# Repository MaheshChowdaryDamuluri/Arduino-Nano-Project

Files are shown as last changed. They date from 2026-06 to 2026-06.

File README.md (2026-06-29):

# ⚡ Custom Arduino Nano Compatible PCB Design Project

Welcome to the official repository for the **Custom Arduino Nano Hardware Clone** project. This repository houses the full programmatic schematic blueprints, advanced multi-layer stackup routing configurations, and fabrication-ready source materials engineered entirely within the KiCad design suite. 

Unlike a standard commercial breakout board, this implementation optimizes power rail stability, enhances differential signal impedance, and introduces precise physical test points for desktop diagnostic verification.

---

## 📐 1. Technical System Architecture

The hardware architecture systematically translates your top-level project settings into specialized component zones designed to reduce trace length and eliminate unwanted parasitic loops:

### 🧠 Core Microcontroller Node (`Arduino nano.kicad_sch`)
* **Processor Unit:** Features a high-performance 8-bit AVR microcontroller housed in an ultra-compact, surface-mount **QFN-32** package footprint.
* **System Clock:** Driven by a precision **16MHz ceramic resonator** (`Murata CSTNE`) to ensure predictable, jitter-free code execution timing.
* **ICSP Header Array:** Breaks out a standard 3-pin In-Circuit Serial Programming (ICSP) interface alongside standard vertical female pin-socket strips for effortless external bootloader flashing and pin mapping.

### 🔌 USB Telemetry & Serial Interface
* **Interface Bridge:** Built around the rugged **FT232RL SSOP-28** USB-to-Serial converter chip, delivering bulletproof stability over long debugging sessions.
* **Upstream Protection:** Protects your computer's USB controller using a resettable surface-mount **0603 Polyfuse** to clamp unexpected short-circuits instantly.
* **Differential Signaling:** Routes raw data lines using precise trace spacing down to test pads (`TP1` and `TP2`) for real-time oscilloscope signal inspection.

### ⚡ Power Supply & Linear Regulation Network
* **DC-DC Step-Down:** Incorporates a dedicated low-dropout (LDO) **LM1117MP-5.0 fixed linear regulator** in a robust SOT-223 package.
* **Filtering Topology:** Employs a multi-stage decoupling matrix combining polarized Tantalum bulk smoothing capacitors ($4.7\mu\text{F}$) with high-frequency $100\text{nF}$ ceramic filtering passives positioned right at the power input boundaries to block supply ripple spikes.
* **Input Isolation:** Implements an internal Schottky reverse-voltage protection diode to safely manage power handover between the external input pin and the desktop USB port.

---

## 🛠️ 2. PCB Layer Stackup & Layout Disciplines

The layout database shifts away from legacy double-sided prototyping to a high-speed **4-layer PCB architecture** configured inside the board setup:

1. **Top Layer (`F.Cu`):** High-density component landing networks and primary signal trace breakouts.
2. **Inner Layer 1 (`In1.Cu`):** Solid Ground Plane (`GND`) serving as a low-impedance return path to significantly reduce EM emissions.
3. **Inner Layer 2 (`In2.Cu`):** Specialized Power Grid distribution plane handling multiple system voltages.
4. **Bottom Layer (`B.Cu`):** Secondary routing pathways and clear status indicators.

* **🎨 Solder Mask Aesthetic:** Formatted for a sleek, premium **Blue Solder Mask** application over high-grade FR4 core material.
* **🚦 Status LEDs:** Incorporates four surface-mount visual telemetry indicators (Yellow for Power tracking, Green for Reset lines, and Red/Green options for system notifications).

---

## 📋 3. Project Bill of Materials (BOM)

| Designator | Component Quantity | Component Value | Package Footprint | Purpose / Function |
| :--- | :---: | :--- | :--- | :--- |
| **U1** | 1 | MCU Core Chip | QFN-32-1EP (5x5mm) | Primary Microcontroller Core |
| **U3** | 1 | FT232RL | SSOP-28_5.3x10.2mm | USB to Serial Communication Bridge |
| **U2** | 1 | LM1117MP-5.0 | SOT-223-3 (TabPin2) | +5V Low-Dropout Regulator |
| **F1** | 1 | Polyfuse (0603) | D_0603_1608Metric | Resettable Overcurrent Protection |
| **Y1** | 1 | 16MHz Resonator | CSTxExxV-3Pin (3.0x1.1mm) | Core Clock Source Oscillator |
| **J1** | 1 | USB_B_Mini | USB_Mini-B_Horizontal | System Power & Programming Interface |
| **SW1** | 1 | SW_Push | Panasonic_EVQPUK_EVQPUB | Master Hardware Reset Button |
| **C4, C9** | 2 | 4u7_16V | CP_EIA-3216-10_Kemet-I | Polarized Tantalum Smoothing Capacitors |
| **C1, C2, C5, C6** | 4 | 1u | C_0603_1608Metric | Ceramic Decoupling Passives |
| **C3, C7, C8, C10** | 4 | 100n | C_0603_1608Metric | High-Frequency Bypass Capacitors |
| **R1 - R7** | 7 | 1k | D_0603_1608Metric | Current Limiting Resistors |
| **D1 - D5** | 5 | LED Colors | LED_0805_2012Metric | Telemetry & Visual Status Indicators |

---

## 📂 4. Repository File Directory
```text
├── Arduino nano.kicad_pro    # Master project settings linking schematics & board layers
├── Arduino nano.kicad_sch    # Top-level interactive hardware electrical schema
├── Arduino nano.kicad_pcb    # Completed physical 4-layer trace layout matrix
├── Arduino nano.kicad_prl    # Project local display preferences & monitor settings
├── .gitignore                # Automatically generated rule patterns filtering out bak files
└── LICENSE                   # MIT Open-Source Hardware Licensing certification

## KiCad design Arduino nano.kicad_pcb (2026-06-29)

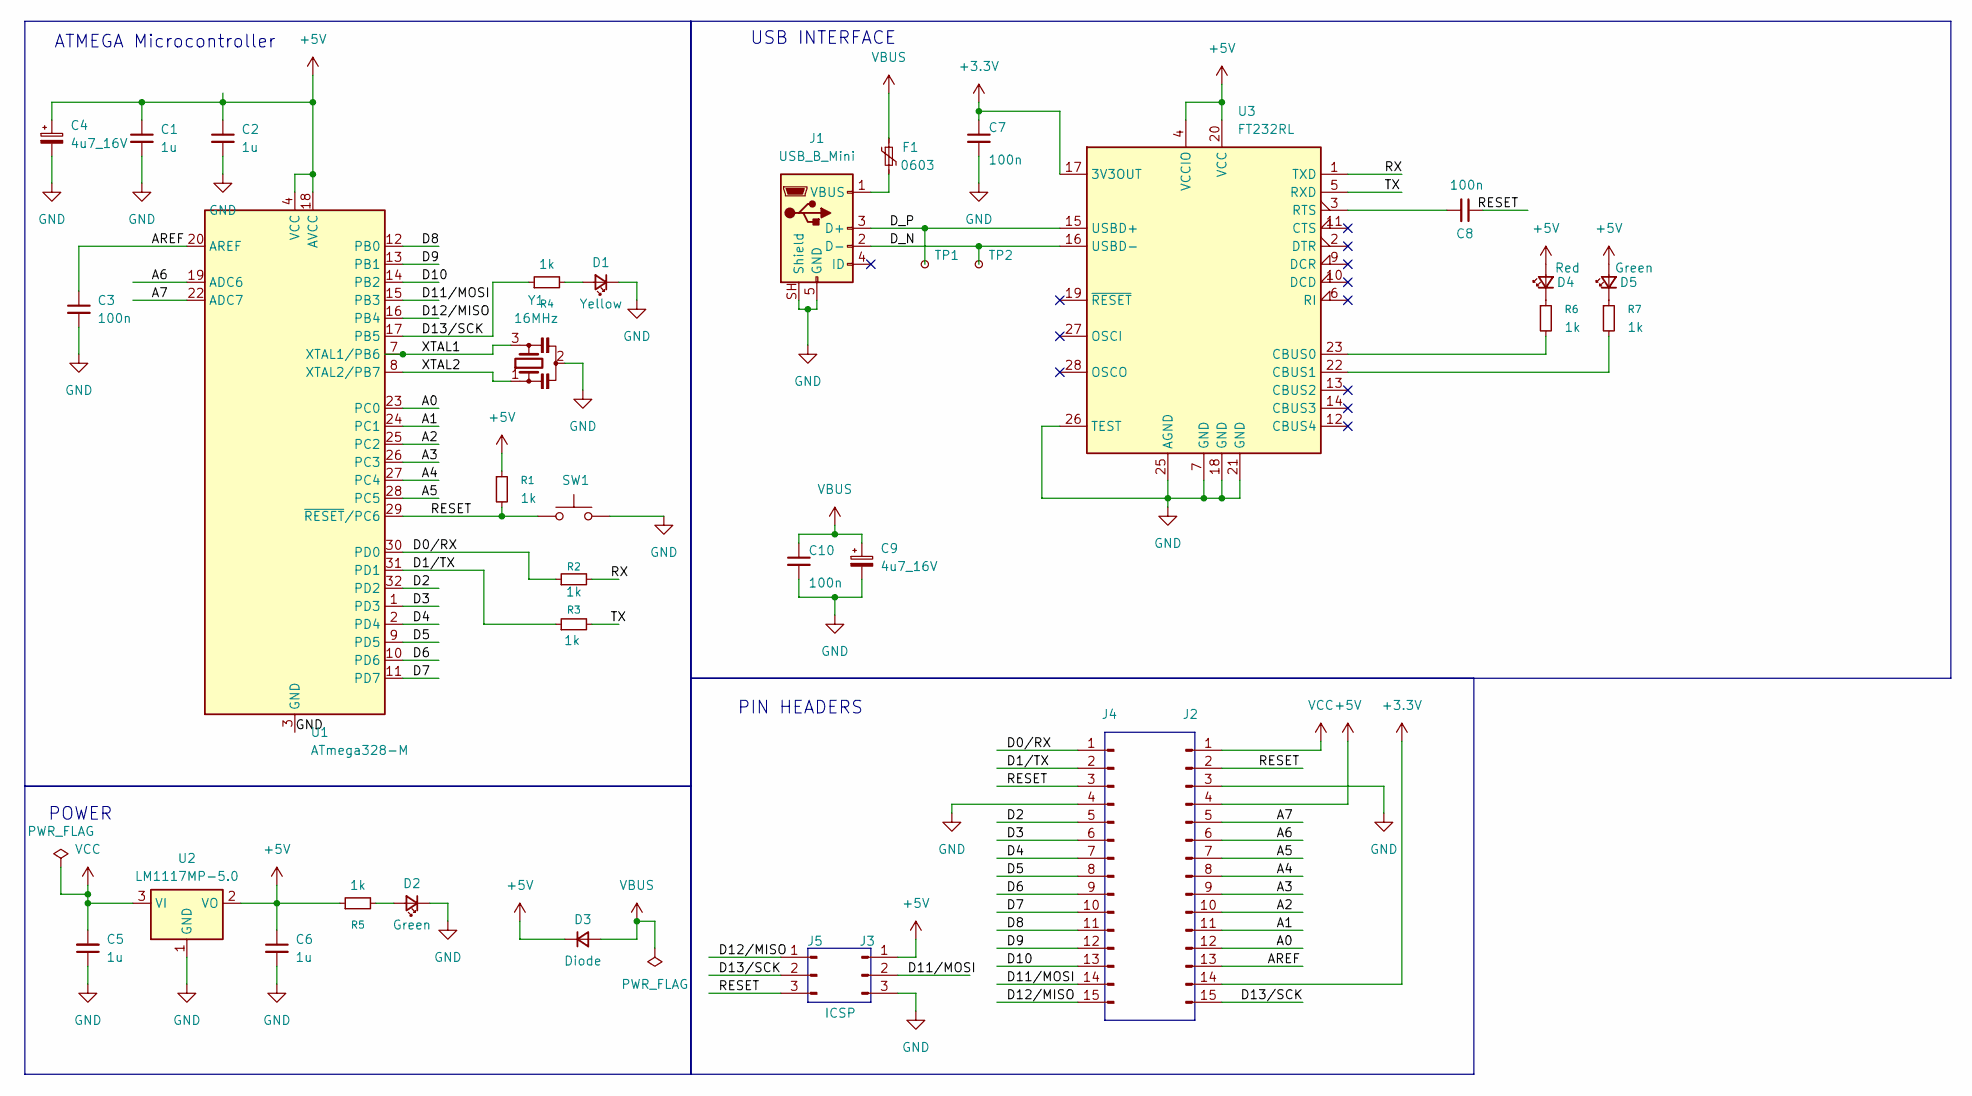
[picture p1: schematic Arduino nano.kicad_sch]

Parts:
C1, C2, C5, C6: 1u; C_0603_1608Metric
C3, C7, C8, C10: 100n; C_0603_1608Metric
C4, C9: 4u7_16V; CP_EIA-3216-10_Kemet-I
D1: Yellow; LED_0805_2012Metric
D2, D5: Green; LED_0805_2012Metric
D3: Diode; D_MicroSMP_AK
D4: Red; LED_0805_2012Metric
F1: 0603; D_0603_1608Metric
J1: USB_B_Mini; USB_Mini-B_Wuerth_65100516121_Horizontal
J2, J4: Conn_01x15_Pin; PinSocket_1x15_P2.54mm_Vertical
J3: ICSP; PinHeader_1x03_P2.54mm_Vertical
J5: Conn_01x03_Pin; PinHeader_1x03_P2.54mm_Vertical
R1, R2, R3, R4, R5, R6, R7: 1k; D_0603_1608Metric
SW1: SW_Push; Panasonic_EVQPUK_EVQPUB
TP1, TP2: TestPoint_Small; TestPoint_Pad_D1.0mm
U1: ATmega328-M; QFN-32-1EP_5x5mm_P0.5mm_EP3.1x3.1mm
U2: LM1117MP-5.0; SOT-223-3_TabPin2
U3: FT232RL; SSOP-28_5.3x10.2mm_P0.65mm
Y1: 16MHz; Resonator_SMD_Murata_CSTxExxV-3Pin_3.0x1.1mm

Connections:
+3.3V: C7.1, J2.14, U3.17 (3V3OUT)
+5V: C1.1, C2.1, C4.1, C6.1, D3.1 (K), D4.2 (A), D5.2 (A), J2.4, J3.1, R1.1, R5.1, U1.4 (VCC), U1.6 (VCC), U1.18 (AVCC), U2.2 (VO), U3.4 (VCCIO), U3.20 (VCC)
/A0: J2.12, U1.23 (PC0)
/A1: J2.11, U1.24 (PC1)
/A2: J2.10, U1.25 (PC2)
/A3: J2.9, U1.26 (PC3)
/A4: J2.8, U1.27 (PC4)
/A5: J2.7, U1.28 (PC5)
/A6: J2.6, U1.19 (ADC6)
/A7: J2.5, U1.22 (ADC7)
/AREF: C3.1, J2.13, U1.20 (AREF)
/D0/RX: J4.1, R2.1, U1.30 (PD0)
/D1/TX: J4.2, R3.1, U1.31 (PD1)
/D2: J4.5, U1.32 (PD2)
/D3: J4.6, U1.1 (PD3)
/D4: J4.7, U1.2 (PD4)
/D5: J4.8, U1.9 (PD5)
/D6: J4.9, U1.10 (PD6)
/D7: J4.10, U1.11 (PD7)
/D8: J4.11, U1.12 (PB0)
/D9: J4.12, U1.13 (PB1)
/D10: J4.13, U1.14 (PB2)
/D11/MOSI: J3.2, J4.14, U1.15 (PB3)
/D12/MISO: J4.15, J5.1, U1.16 (PB4)
/D13/SCK: J2.15, J5.2, R4.1, U1.17 (PB5)
/D_N: J1.2 (D-), TP2.1, U3.16 (USBD-)
/D_P: J1.3 (D+), TP1.1, U3.15 (USBD+)
/RESET: C8.1, J2.2, J4.3, J5.3, R1.2, SW1.1, U1.29 (~RESET/PC6)
/RX: R2.2, U3.1 (TXD)
/TX: R3.2, U3.5 (RXD)
/XTAL1: U1.7 (XTAL1/PB6), Y1.3
/XTAL2: U1.8 (XTAL2/PB7), Y1.1
GND: C1.2, C2.2, C3.2, C4.2, C5.1, C6.2, C7.2, C9.2, C10.2, D1.1 (K), D2.1 (K), J1.5 (GND), J1.6 (Shield), J1.SH (Shield), J2.3, J3.3, J4.4, SW1.2, U1.3 (GND), U1.5 (GND), U1.21 (GND), U1.33 (GND), U2.1 (GND), U3.7 (GND), U3.18 (GND), U3.21 (GND), U3.25 (AGND), U3.26 (TEST), Y1.2
unnamed: D1.2 (A), R4.2
unnamed: D2.2 (A), R5.2
unnamed: D4.1 (K), R6.1
unnamed: D5.1 (K), R7.1
unnamed: F1.2, J1.1 (VBUS)
unnamed: R6.2, U3.23 (CBUS0)
unnamed: R7.2, U3.22 (CBUS1)
unnamed: C8.2, U3.3 (RTS)
VBUS: C9.1, C10.1, D3.2 (A), F1.1
VCC: C5.2, J2.1, U2.3 (VI)

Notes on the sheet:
ATMEGA Microcontroller
PIN HEADERS
POWER
USB INTERFACE

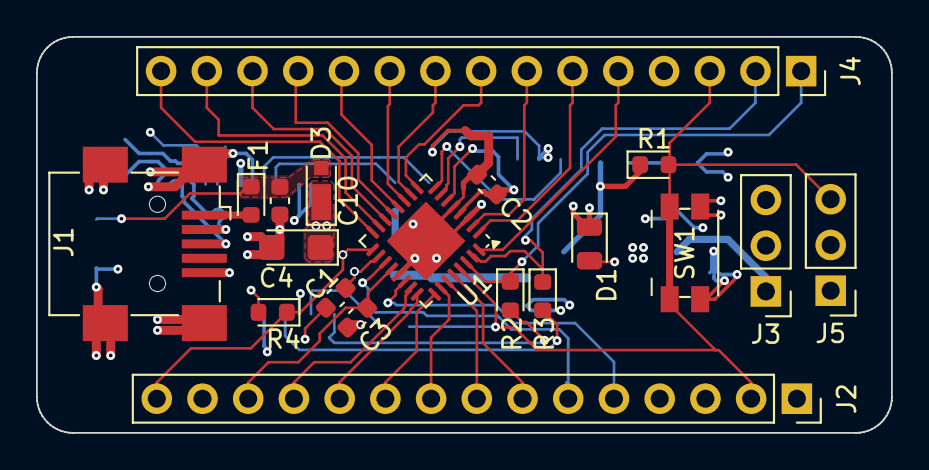
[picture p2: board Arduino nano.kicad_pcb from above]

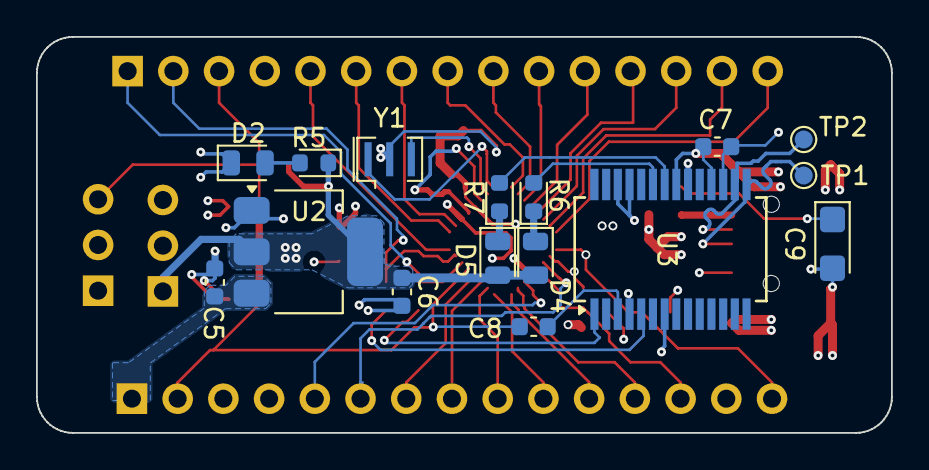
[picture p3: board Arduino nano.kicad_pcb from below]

Board: 4 copper layers, 47.5 x 22.0 mm, 35 parts (16 on the bottom side), 43 nets.
